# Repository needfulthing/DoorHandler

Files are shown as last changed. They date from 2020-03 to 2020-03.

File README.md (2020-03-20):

# DoorHandler v3

This is the third version of the Door Handler. For previous development steps see my instructables "The Door Handler" and "The Door Handler v2".

Improvements:
- The lids are a bit larger and fit better over the jaws now.

- The lid's rubber band slots moved a bit to the back to reduce tension when using a 60mm rubber band.

- Hot glue is used on the inner of the jaws to add a smooth and grippy surface.

- Added 3D objects for a pocket holder. Four 6 x 2.8mm Neodym magnets are required for the pocket holder and the handler itself.

- Added left hand and right hand version so you can wear it on both sides.

I consider this the first version which might be really usable. Though I don't feel the urge to make the design more complicated a version with UV integrated LEDs roams in my mind. Maybe I will go for it the next days.

# Printing

Print all the parts, which is one handler (left or right), one handler holder (left or right), both lids and one pocket holder clip. Choose either left hand or right hand version for the handler and the handler holder.

Print settings:

- 0.4 mm nozzle

- 0.15 mm layer height

- 15% Gyroid infill

- a brim is recommended

- I used PLA for these prints

# Add Grip

Add hot glue to the inner area of the jaws. Try to make a smooth grip surface.

# Add Rubber Band

Thread the rubber band trough the holes on both lids as shown in the picture.

# Mount Screw

Align the band over the thumb rest, then move the lid screw holes over the mounting hole of the front jaw. Attach the screw. To avoid that the nut loosens though usage you can put some glue on the screw/nut junction.

# Attach Magnets

Push two magnets into the holes of the handler holder and two magnets into the associated holes of the handler grip.

IMPORTANT NOTE: Check the polarity of the other two magnets before pushing them in, so that both magnet pairs attract each other properly!

IMPORTANT NOTE 2: The pictures still show a prototype with only two magnets, but I found out that one pair didn't make the handler stick firm enough to the holder. The 3D files already include another magnet hole pair.

# Hot Glue the Holder and Clip.

Hot glue the handler holder to the holder clip.

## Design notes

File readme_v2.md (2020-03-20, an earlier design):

This is the next version of the door handler. It makes the design more complicated, but adds valuable protection lids on both sides to avoid touching the area that gets in contact with the handle. Next step will be an outside pocket holder with magnets so it must not be carried in a pocket anymore. I hope this will raise safety more so it might become a usable tool. Also the lids are not perfectly aligned yet, not covering the jaws perfectly. I will improve this too. For information about the whole development process and concerns see the previous project "The Door Handler".

There are two lids now that turn around a single axis (a fixing screw) in the front of the tool. I re-used the rubber band holder from the first version used for wrapping rubber bands around the tool's jaws for better friction. I dropped that friction enhancement part for now. The carving now holds a single rubber band connected to the lids that retracts the lids to the default position. If you push the tool over a handle the lids get pushed back allowing to grab the handle and they retract, when you pull away the tool from the handle.

You now also need one M3 screw of the length 22mm to 24mm with a counterpart nut. I currently use a much too long dummy screw for testing, but I ordered some 22mm M3 and also some M3 cap nuts which will fit better.

Supplies:
3D printer, PLA

One M3 screw 22-24mm and one M3 nut

Household rubber band (>60mm in loose state)

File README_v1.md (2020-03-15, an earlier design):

# DoorHandler

This is a project I made after I got annoyed by performing break-dance when trying to open doors without touching the handle. It's just a quick shot on the problem and surely can be improved in quite some ways, but the focus was on creating a simple and easy to print (or to build in other ways) tool without using up too much time. Maybe it's a silly idea, but I find it's at least better than using your sleeves or elbows. There is a little carving to add rubber bands to get better friction and to protect the door when you push it with the tool, but currently the bands tend to peel off when stashing or removing the handler in and out of the jeans watch pocket. There is a hole for attachment but that might only make sense with a retracting line. I will make another version tomorrow with some more rounding on the edges to protect the rubber band to get cut and a deeper carving for the bands so they don't slide of. Right now you might work a little on the edges of the finished print and smooth them with sand paper. Some more ideas would be to maybe make a rubber band retractable lid for the front part that touches the handle or maybe a (magnet) belt holder. The thumb rest might also be better if it's a little bit lower. Another idea was to reduce the touching area by adding a triangle edge inside the front u-shaped part. So you see I left some things for you to go on with it if you like :-)

=== Notes on Cleaning PLA

PLA is not the best material to clean: the printed surface is not totally even and although you can rinse it with boiled water for some seconds without a problem, you can't cover it with it. The PLA will get soft in a short time due to the heat therefore dish washers are also no option. Ethanol is possible but I read it tends to make PLA brittle over time. Maybe coating the tool with some protective layer like spray paint could help.

=== Important Note about Stability and Print Settings

For the print I used 15% filling with the wonderful Gyroid pattern and it seems to be quite stable though I DID NOT TRY OUT THE FORCE IT TAKES TO BREAK IT. You might want to experiment with a higher filling density. The print nozzle was 0.4mm and layer height was 0.15mm. With this settings it uses up around 5 meters of PLA and takes about 1 hour and 40 minutes on an MK3s.

=== Together

I publish this under the GNU GPL for everyone to copy, use, develop and share.

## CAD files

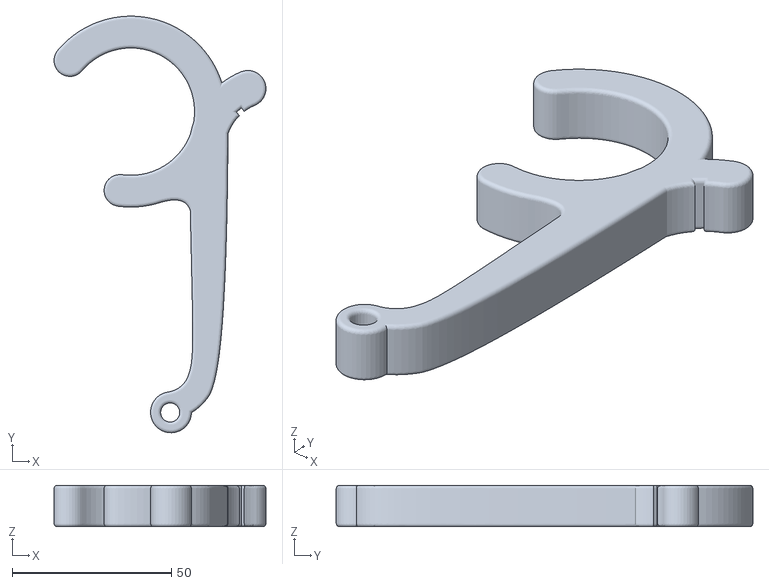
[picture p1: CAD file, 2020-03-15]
DoorHandler.stl
66.6 x 130.9 x 13.0

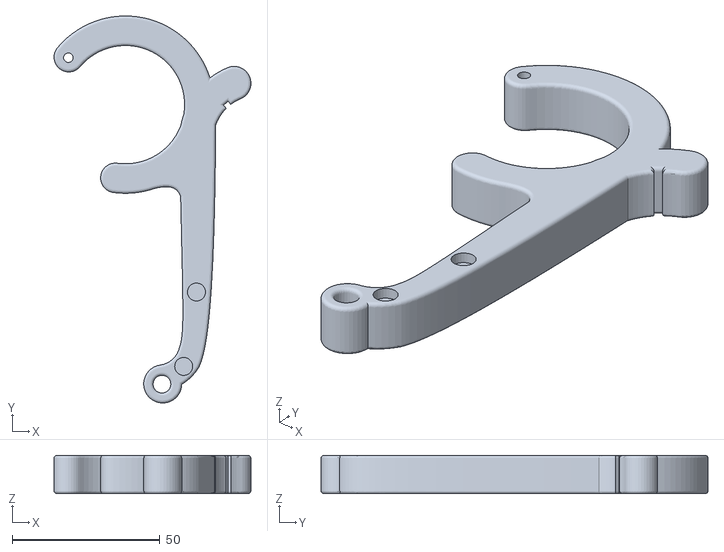
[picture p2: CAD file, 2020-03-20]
v3/DoorHandlerRightHandv3.stl
66.6 x 130.9 x 13.0

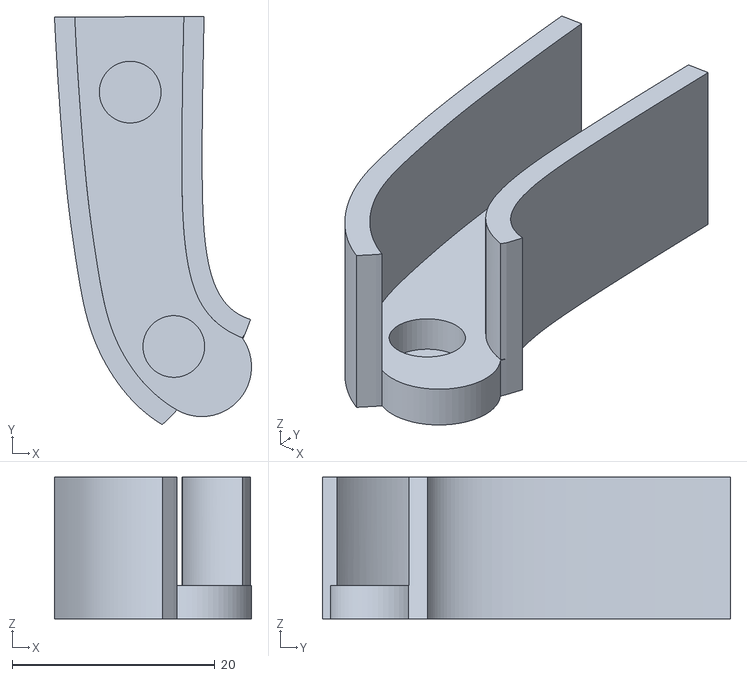
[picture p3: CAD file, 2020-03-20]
v3/PocketHolderRightv3.stl
19.5 x 40.3 x 14.0

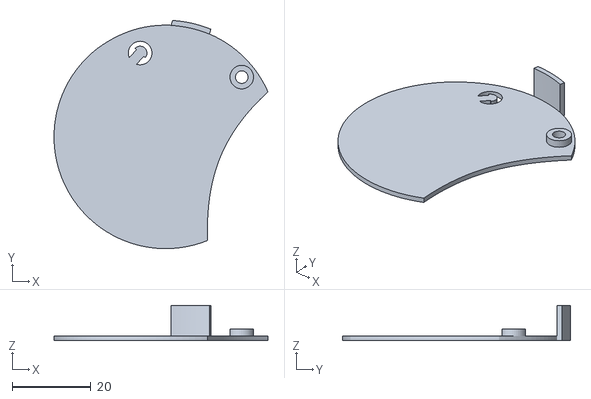
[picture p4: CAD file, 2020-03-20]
v3/LidLeftv3.stl
54.4 x 58.0 x 9.00

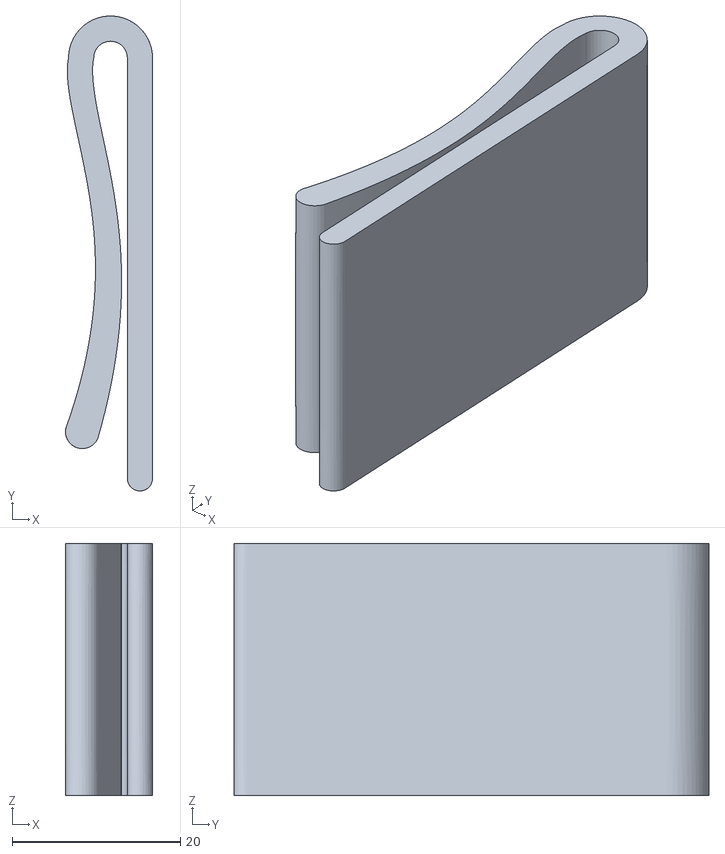
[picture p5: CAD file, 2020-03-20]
v3/PocketHolderClipv3.stl
10.4 x 56.5 x 30.0

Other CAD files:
v3/DoorHandlerLeftHandv3.stl
v3/LidRightv3.stl
v3/PocketHolderLeftv3.stl

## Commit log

2020-03-15 Added STL
    [DoorHandler.stl]
2020-03-20 Added v3
    [DoorHandlerLeftHandv3.stl, DoorHandlerRightHandv3.stl, LidLeftv3.stl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]
